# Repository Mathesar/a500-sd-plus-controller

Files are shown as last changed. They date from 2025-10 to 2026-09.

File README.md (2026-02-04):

# a500-sd-plus-controller
This is a dual micro-SD card plus Ethernet controller for the Amiga 500.
The controller piggybacks on the odd CIA (CIA A) chip on the Amiga 500 motherboard.

## Table of Contents
* [Micro-SD](#micro-sd)
* [Ethernet](#ethernet)
* [Drivers](#drivers)
* [Performance](#performance)
* [Pictures](#pictures)
* [Building](#building)

## Micro-SD
The two Micro-SD cards are operated in SPI mode.
Using the 68000 movep (move to/from peripheral) instruction and optimized code the driver reaches a raw throughput of up to 450kB/s on a standard 7MHz 68000 CPU. Due to device driver and filesystem overhead the overall speed is lower though.

The primary channel is intended for internal use. The micro-SD card in this slot functions as a fixed harddisk. The secondary channel is intended to be used with an extension cable to hold an external (hot-swappable if the driver supports it) micro-SD card. 
For this purpose, proper measures are taken to control signal integrity over the extension cable. The controller can also handle any current surges that can occur during hot swapping without overloading the Amiga power rail.

## Ethernet
The Ethernet controller is a Microchip ENC28J60 device. It is also connected over SPI and uses the INT2 interrupt. The ENC28J60 supports a 10Mbit network connection.
The interface is built in a slightly non-standard way to maximum immunity for external interference.

## Drivers
The Micro-SD cards are supported by [sd-lide.device](https://github.com/Mathesar/sd_lide.device).

The Ethernet controller is supported by [enc28j60.device](https://github.com/Mathesar/enc28j60.device).

## Performance
On a standard Amiga 500 with a 7MHz 68000 CPU running OS3.1 and AmiTCP 3.0b2 the following performance is reached:

* 250kB/s read speed for the Micro-SD cards as reported by SysInfo.
* Up to 22kB/s network download speed which is mostly limited by CPU speed.

Much better performance which is only limited by the speed of the E-clk (~600..700kB/s) can be expected when a faster CPU is installed.

## Pictures
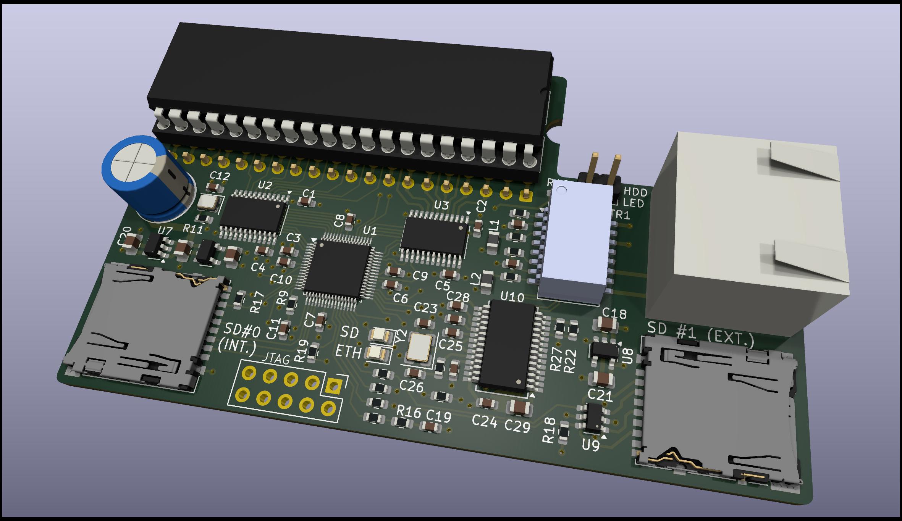
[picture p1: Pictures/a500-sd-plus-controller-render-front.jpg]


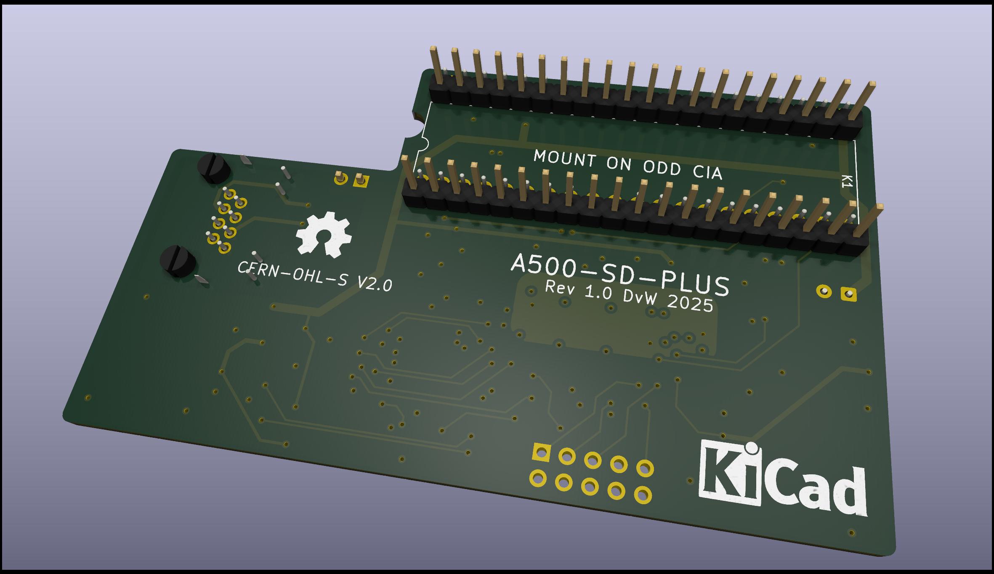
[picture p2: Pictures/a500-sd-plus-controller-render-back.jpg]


Proof that this was actually built:
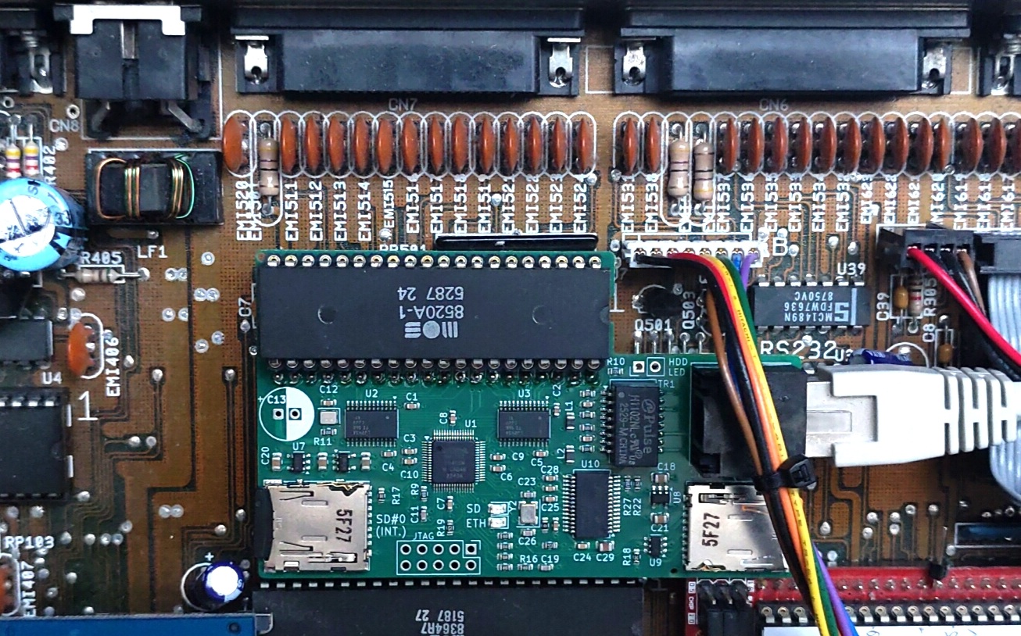
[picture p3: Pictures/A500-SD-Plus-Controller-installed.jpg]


And the obligatory SysInfo screenshot:
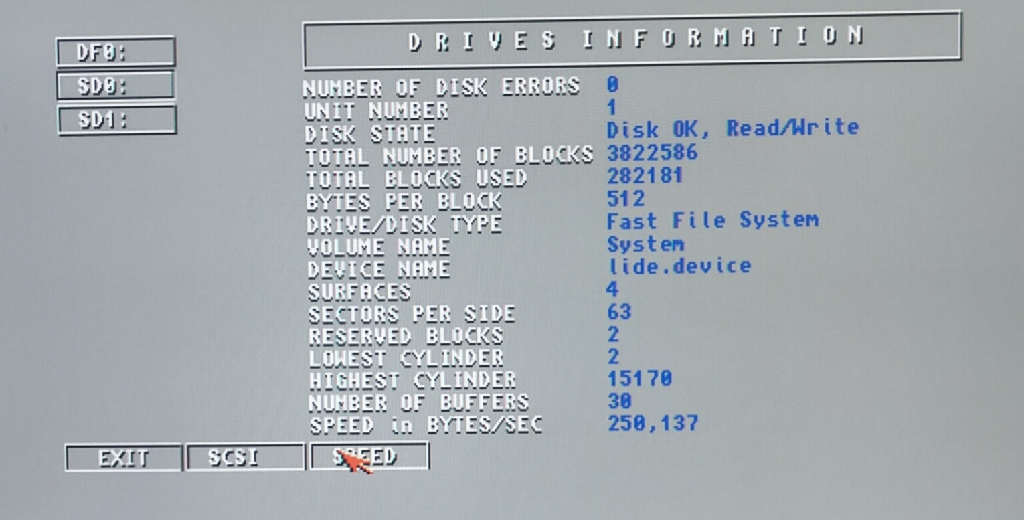
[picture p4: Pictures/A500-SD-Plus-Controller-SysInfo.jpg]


## Building
Under [releases](https://github.com/Mathesar/a500-sd-plus-controller/releases) you will find the latest gerbers, bill of materials, bitstream, etc.
The files are in a format that is suitable for most well-known PCBA manufacturers.
I would recommend having the boards soldered professionally. This project uses small compononents and especially the CPLD is not solderable by hand. I had the boards made with all the SMD parts and the ethernet connector mounted. I only soldered the pinheaders and the CIA socket myself. For the pinheaders that plug into the CIA socket on the A500 motherboard, be sure to use the THIN and ROUND (aka "turned") pinheaders. Otherwise the motherboard socket WILL be damaged.

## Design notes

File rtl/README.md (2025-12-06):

# a500-sd-plus-controller
The SPI controller communicates via the unused register of the odd 8520 CIA at address $BFEB01

| **address** | **R/W** | **Name** |
| --- | --- | --- |
| $BFEB01 | R/W | SPI controller |

All communication with the SPI controller is done via this single register.
The behavior of this register depends on the state the SPI controller is in.

Additionally, a simple IRQ controller is included that is able to mask interrupts from the ENC28J60 Ethernet controller.

## States
The SPI controller can be in any of the following states:

| **State** | **Read** | **Write** |
| --- | --- | --- |
| IDLE | read busy flag | issue command |
| READ | read buffer and shift | return to **IDLE** |
| WRITE | read buffer and return to **IDLE** | write buffer and shift |
| CRC | read crc | return to **IDLE** |

### IDLE state
In this state, commands can be send the the SPI controller.
After reset, the controller will be in this state.
A command is 1 byte long. 
The following commands are supported:

| **command** | **format**  | **description** |
| --- | --- | --- |
| NOP | 0b000x_xxxx | does nothing |
| CONTROL | 0b001x_xxDD | write control register with 0bDD |
| SELECT | 0b010x_xDDD | write select register with 0bDDD |
| CRC_SOURCE  | 0b011x_xxxD | write crc-source register with 0bD |
| READ | 0b100x_xxxx | goto READ state |
| WRITE | 0b101x_xxxx | goto WRITE state |
| CRC | 0b110x_xxxx | goto CRC state |

When in IDLE mode, a read will return the busy flag in the highest bit (bit#7), the other bits are undefined and should thus be masked out and ignored. 
When the busy flag is set, the controller is doing an SPI transaction and no data should be read from or written to the buffer.

#### select register
This register controls the chip select signals. 
This register is set to all zeroes after reset.
Writing a '1' to a corresponding bit asserts (sets low) the corresponding chip select signal. Only 1 device at a time should be asserted.

| **Bit:** | 2 | 1 | 0 |
| --- | --- | ---- | ---- |
| **Device** | Ethernet | SD 1 | SD 0 |

#### control register
This register controls the configuration of the SPI controller.
This register is set to all zeroes after reset.
Currently, only the SPI clock speed can be set.

| **value** | **clock speed** |
| --- | --- |
| 0b00 | 242 kHz |
| 0b01 | 1.6 MHz |
| 0b10 | 8 MHz |

#### crc-source register
This register selects MOSI or MISO as the CRC generator input. 
This register is set to all zeroes after reset.
Changing the source (writing to this register) also resets the CRC generator to 0x0000.

| **value** | **source** |
| --- | --- |
| 0b0 | MOSI (compute CRC on write) |
| 0b1 | MISO (compute CRC on read)  |

### READ state
This mode is used to read consecutive bytes from the SPI interface.
Each read cycle return the buffer (which contains the last shifted in data) and starts a new SPI transaction. During this transaction, 1's are shifted out regardless of the buffer contents. When the highest speed is selected, data can be read consecutively without checking the busy flag for maximum throughput. For reading a single byte, the WRITE state should be used.

### WRITE state
This mode is used to write a single byte or consecutive bytes to the SPI interface.
Each write cycle writes the buffer and starts a new SPI transaction. During this transaction. When the highest speed is selected, data can be written consecutively without checking the busy flag for maximum throughput.
A read cycle returns the current buffer contents and also returns to the IDLE state.
This way, single bytes can be read as writing in the READ state will always trigger a new SPI transaction.

### CRC state
This mode is used to read the CRC register. The CRC register is 16bits wide. After entering this state from IDLE using the proper command, code should read 2 bytes after which the controller will automatically return to the IDLE state. The first byte read is the high byte of the CRC register. The second byte read is the low byte of the CRC register.

## Some command sequences

### Init sequence, return to IDLE state from an unknown state
```
READ			// return to IDLE state if in CRC or WRITE state
WRITE 0x00  	// if we were now in READ state, return to IDLE state
				// if we are now in IDLE state, issue NOP command
```

### Read a single byte
```
WRITE 0xA0			// go to WRITE state
WRITE 0xFF			// start an SPI transaction while shifting out 1's
READ 				// return to IDLE
while READ&0x80;	// loop while busy set
WRITE 0xA0			// go to WRITE state
READ data;			// read data
```

### Write a single byte
```
WRITE 0xA0			// go to WRITE state
WRITE data			// start an SPI transaction while shifting out data
READ 				// return to IDLE
while READ&0x80;	// loop while busy set
```

## IRQ controller
The IRQ controller allows masking of the ENC28J60 interrupt.
The IRQ controller communicates via the unused bit5 of the odd 8520 CIA's IRC register at address $BFED01

| 7 | 6 | 5 | 4 | 3 | 2 | 1 | 0 |
| --- | --- | --- | --- | --- | --- | --- | --- |
| S/C | | ETH | FLG | SERIAL | TOD | TB  | TA  |

It is not possible to read if the Ethernet interrupt bit was set as this will also clear the CIA's interrupts. So, the Ethernet driver shall only write to this bit.

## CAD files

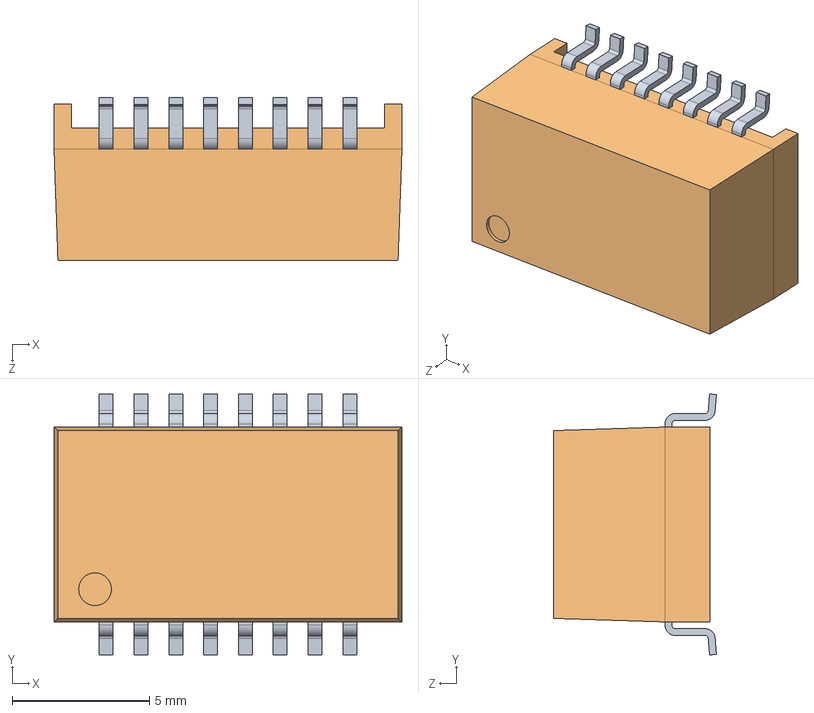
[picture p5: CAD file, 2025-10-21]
kicad/a500-sd-plus-controller/3d/H1102NLT.step
12.7 x 9.53 x 5.94 mm

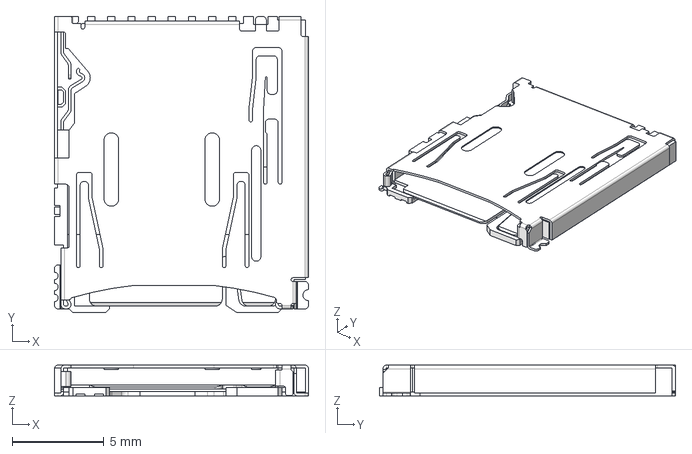
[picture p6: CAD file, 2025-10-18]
kicad/a500-sd-plus-controller/3d/DM3AT-SF-PEJM5.stp
13.8 x 16.2 x 1.68 mm

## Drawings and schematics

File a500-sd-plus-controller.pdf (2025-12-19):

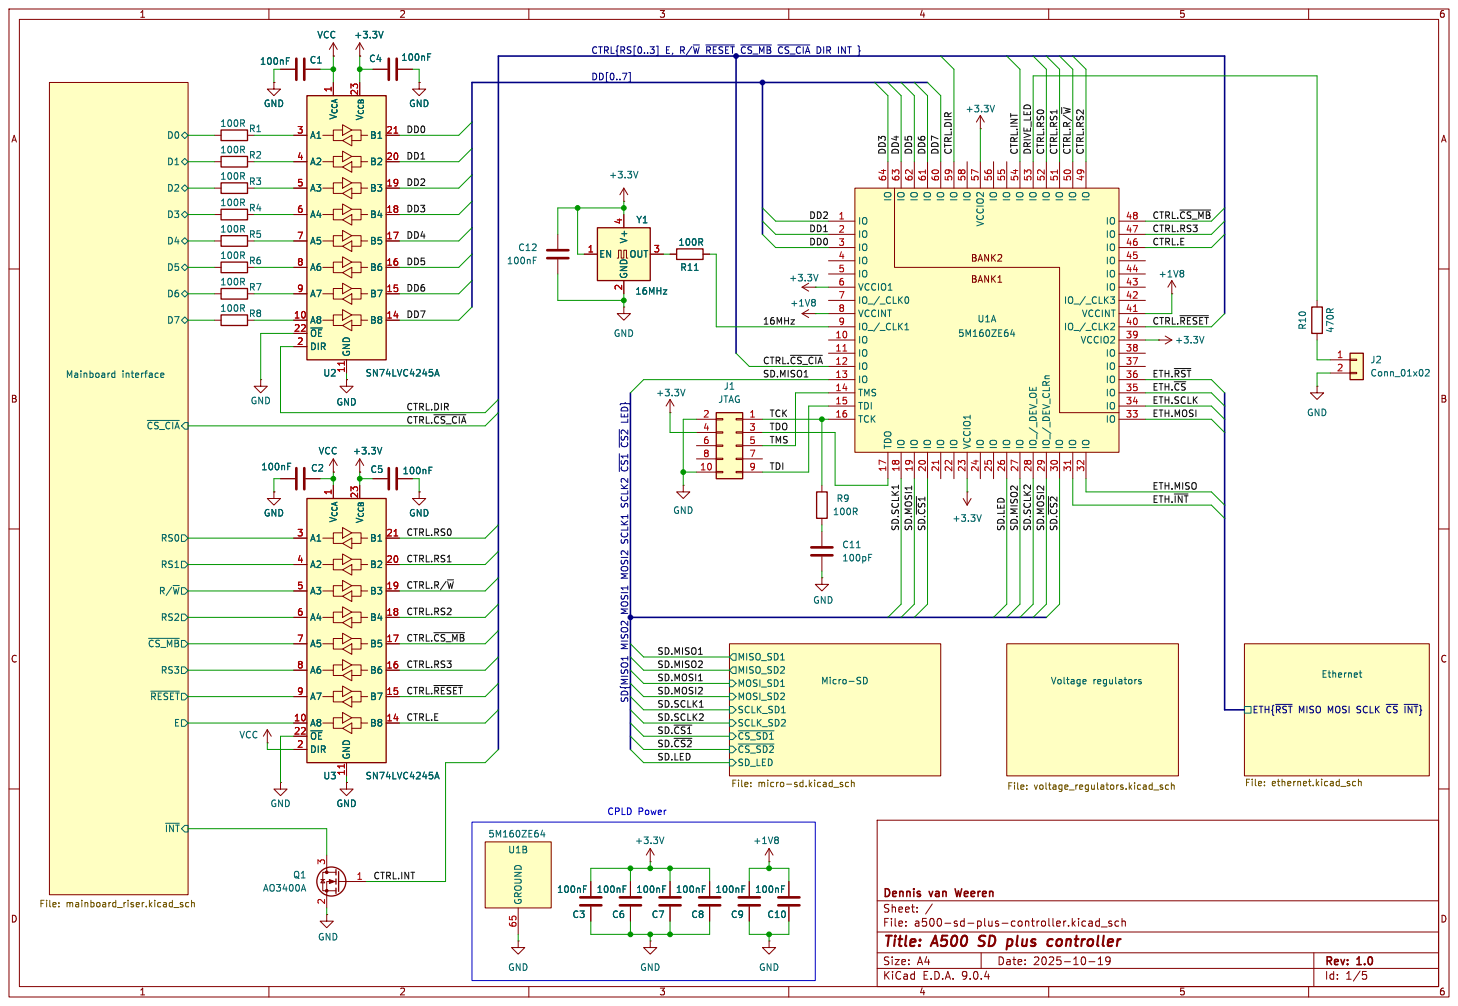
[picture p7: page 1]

SD.MISO1 CTRL.~{CS_CIA} TDI DD[0..7]

CTRL.~{RESET} CTRL.RS3 CTRL.~{CS_MB} CTRL.RS1 CTRL.E CTRL.DIR

ETH.~{RST} SD.~{CS2} SD{MISO1 MISO2 MOSI1 MOSI2 SCLK1 SCLK2 ~{CS1}~{CS2}LED}

ETH{~{RST}MISO MOSI SCLK ~{CS}~{INT}} Ethernet File: ethernet.kicad_sch MISO_SD1 MISO_SD2 MOSI_SD1 MOSI_SD2 SCLK_SD1 SCLK_SD2 ~{CS_SD1}

File: micro-sd.kicad_sch GND

Id: 1/5 Title: A500 SD plus controller File: a500-sd-plus-controller.kicad_sch Sheet: / Dennis van Weeren

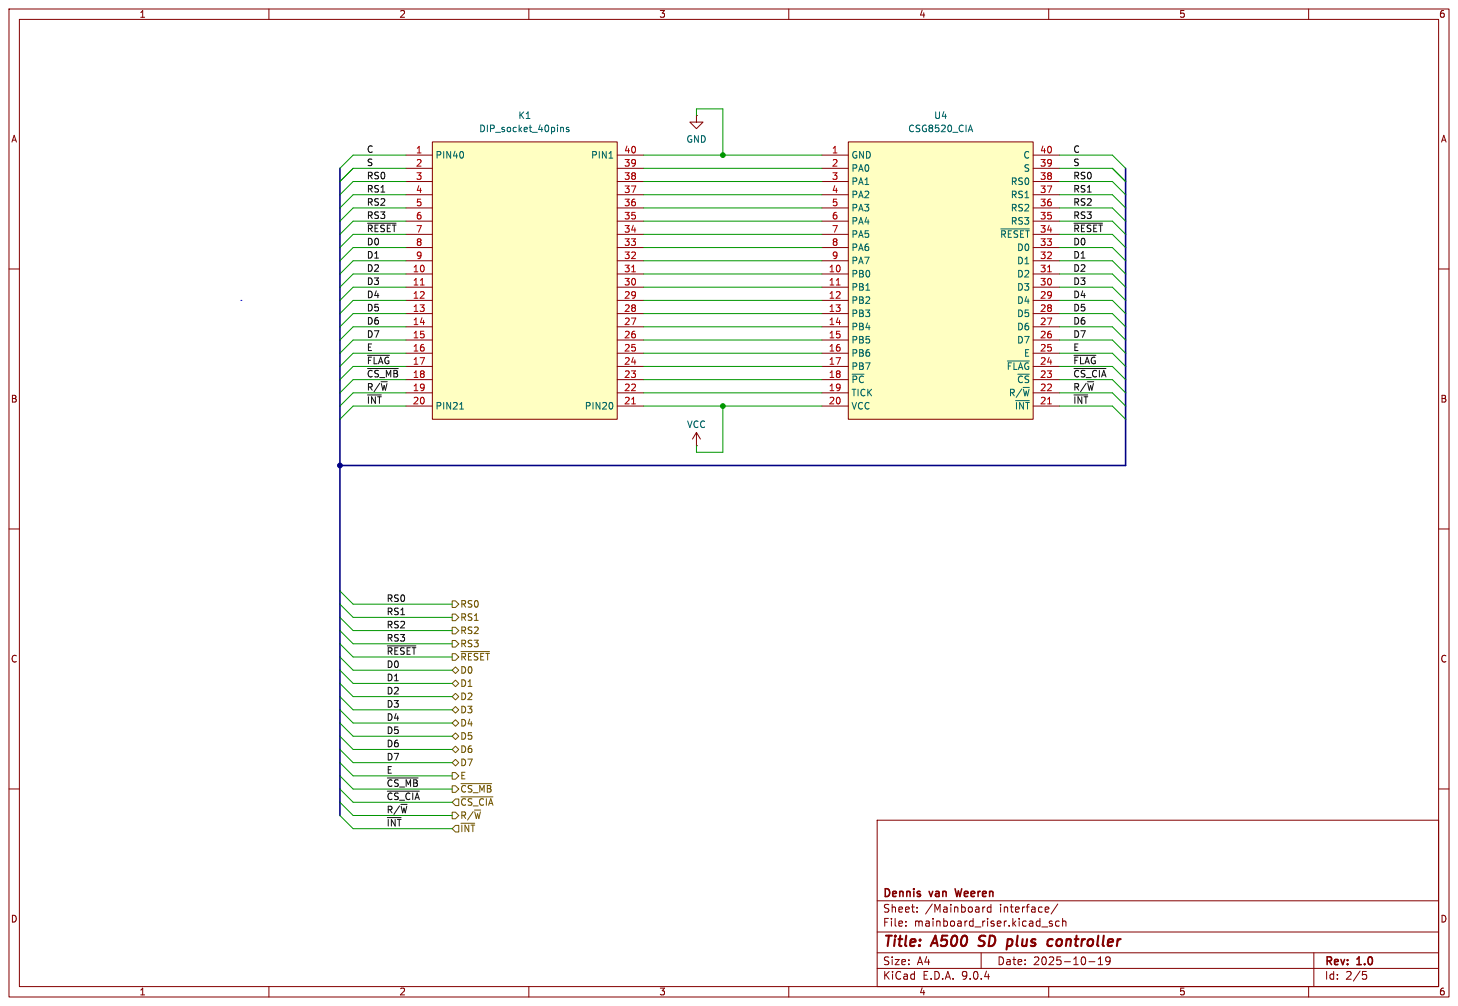
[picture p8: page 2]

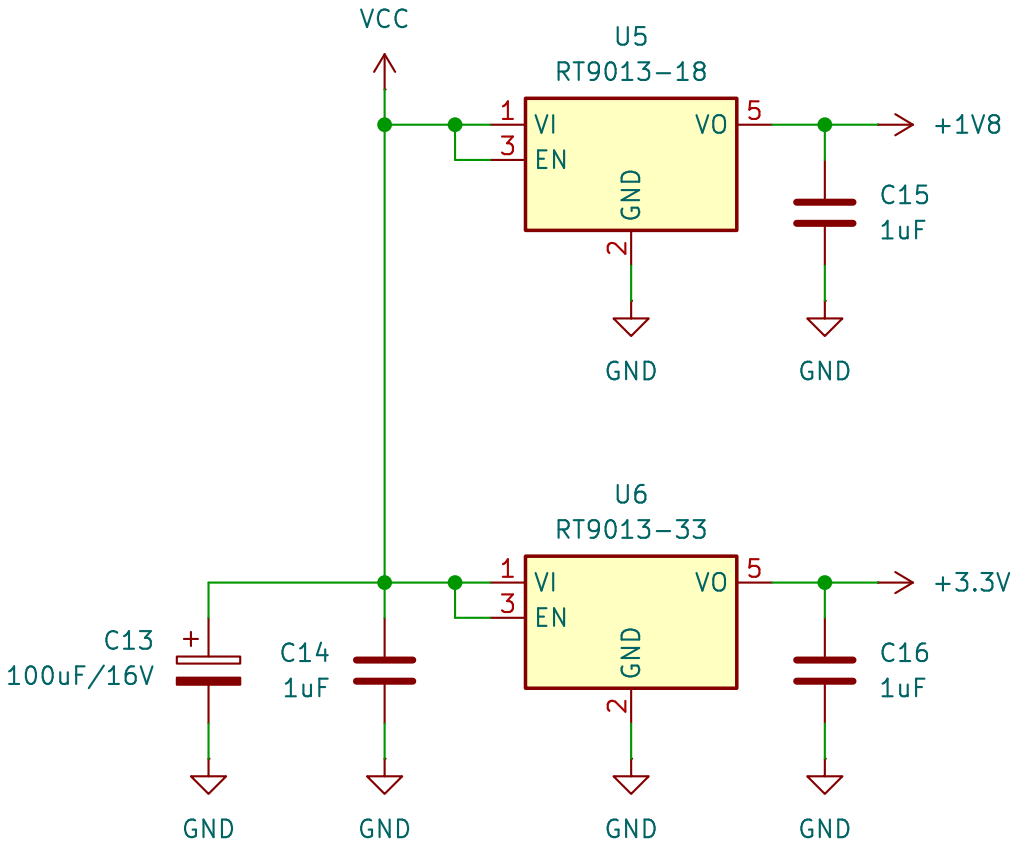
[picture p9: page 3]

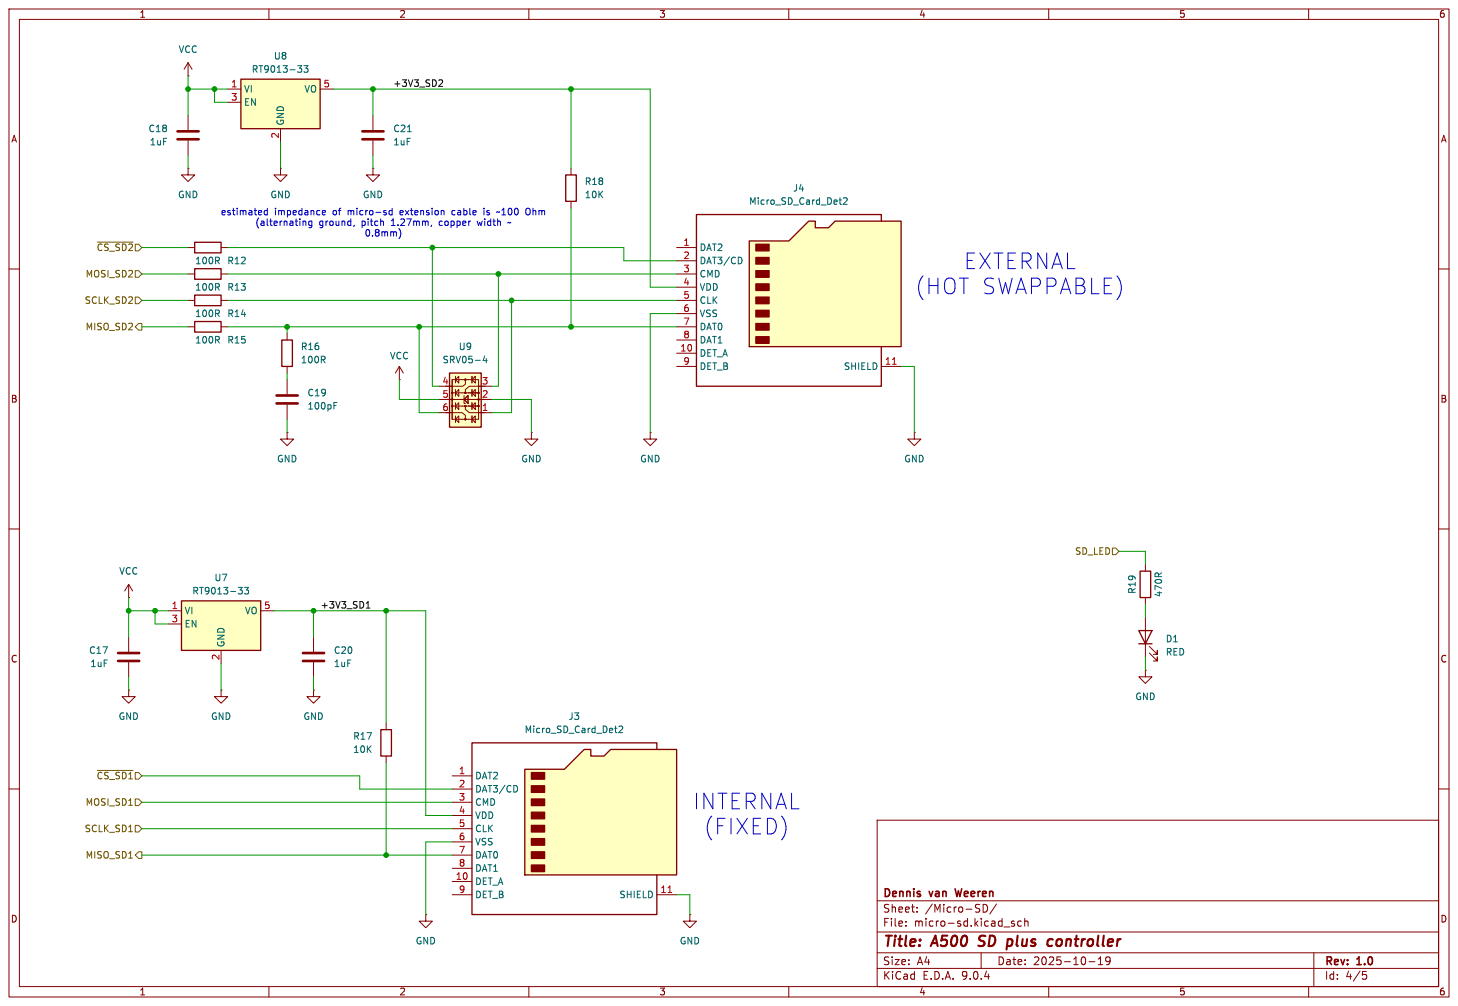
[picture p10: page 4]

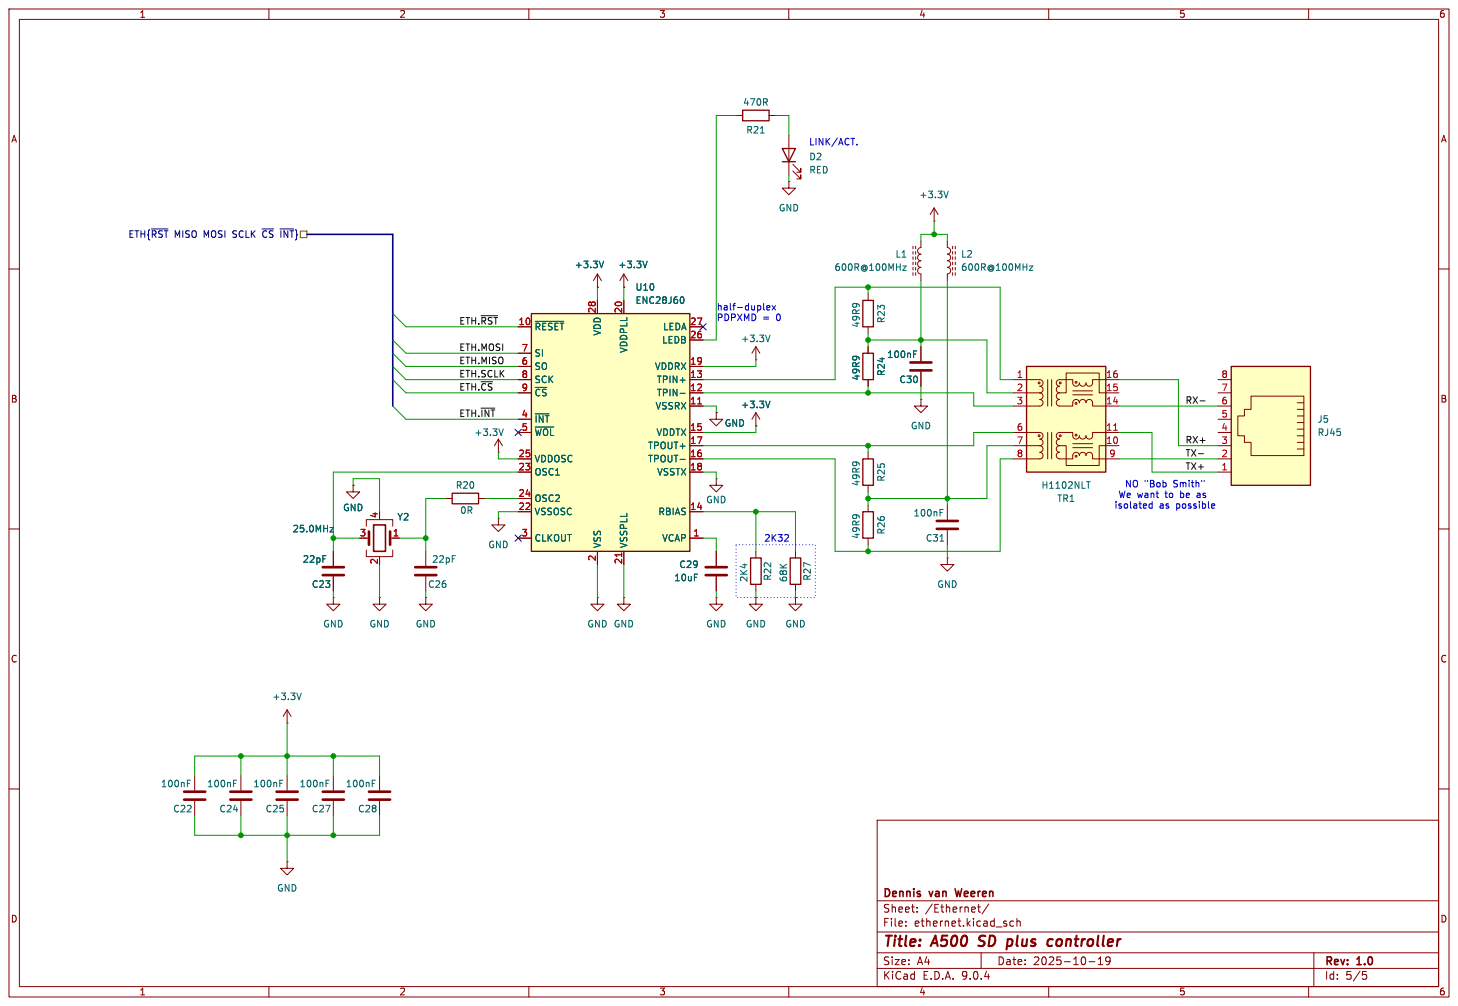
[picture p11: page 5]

Id: 5/5 Title: A500 SD plus controller File: ethernet.kicad_sch Sheet: /Ethernet/ Dennis van Weeren C25

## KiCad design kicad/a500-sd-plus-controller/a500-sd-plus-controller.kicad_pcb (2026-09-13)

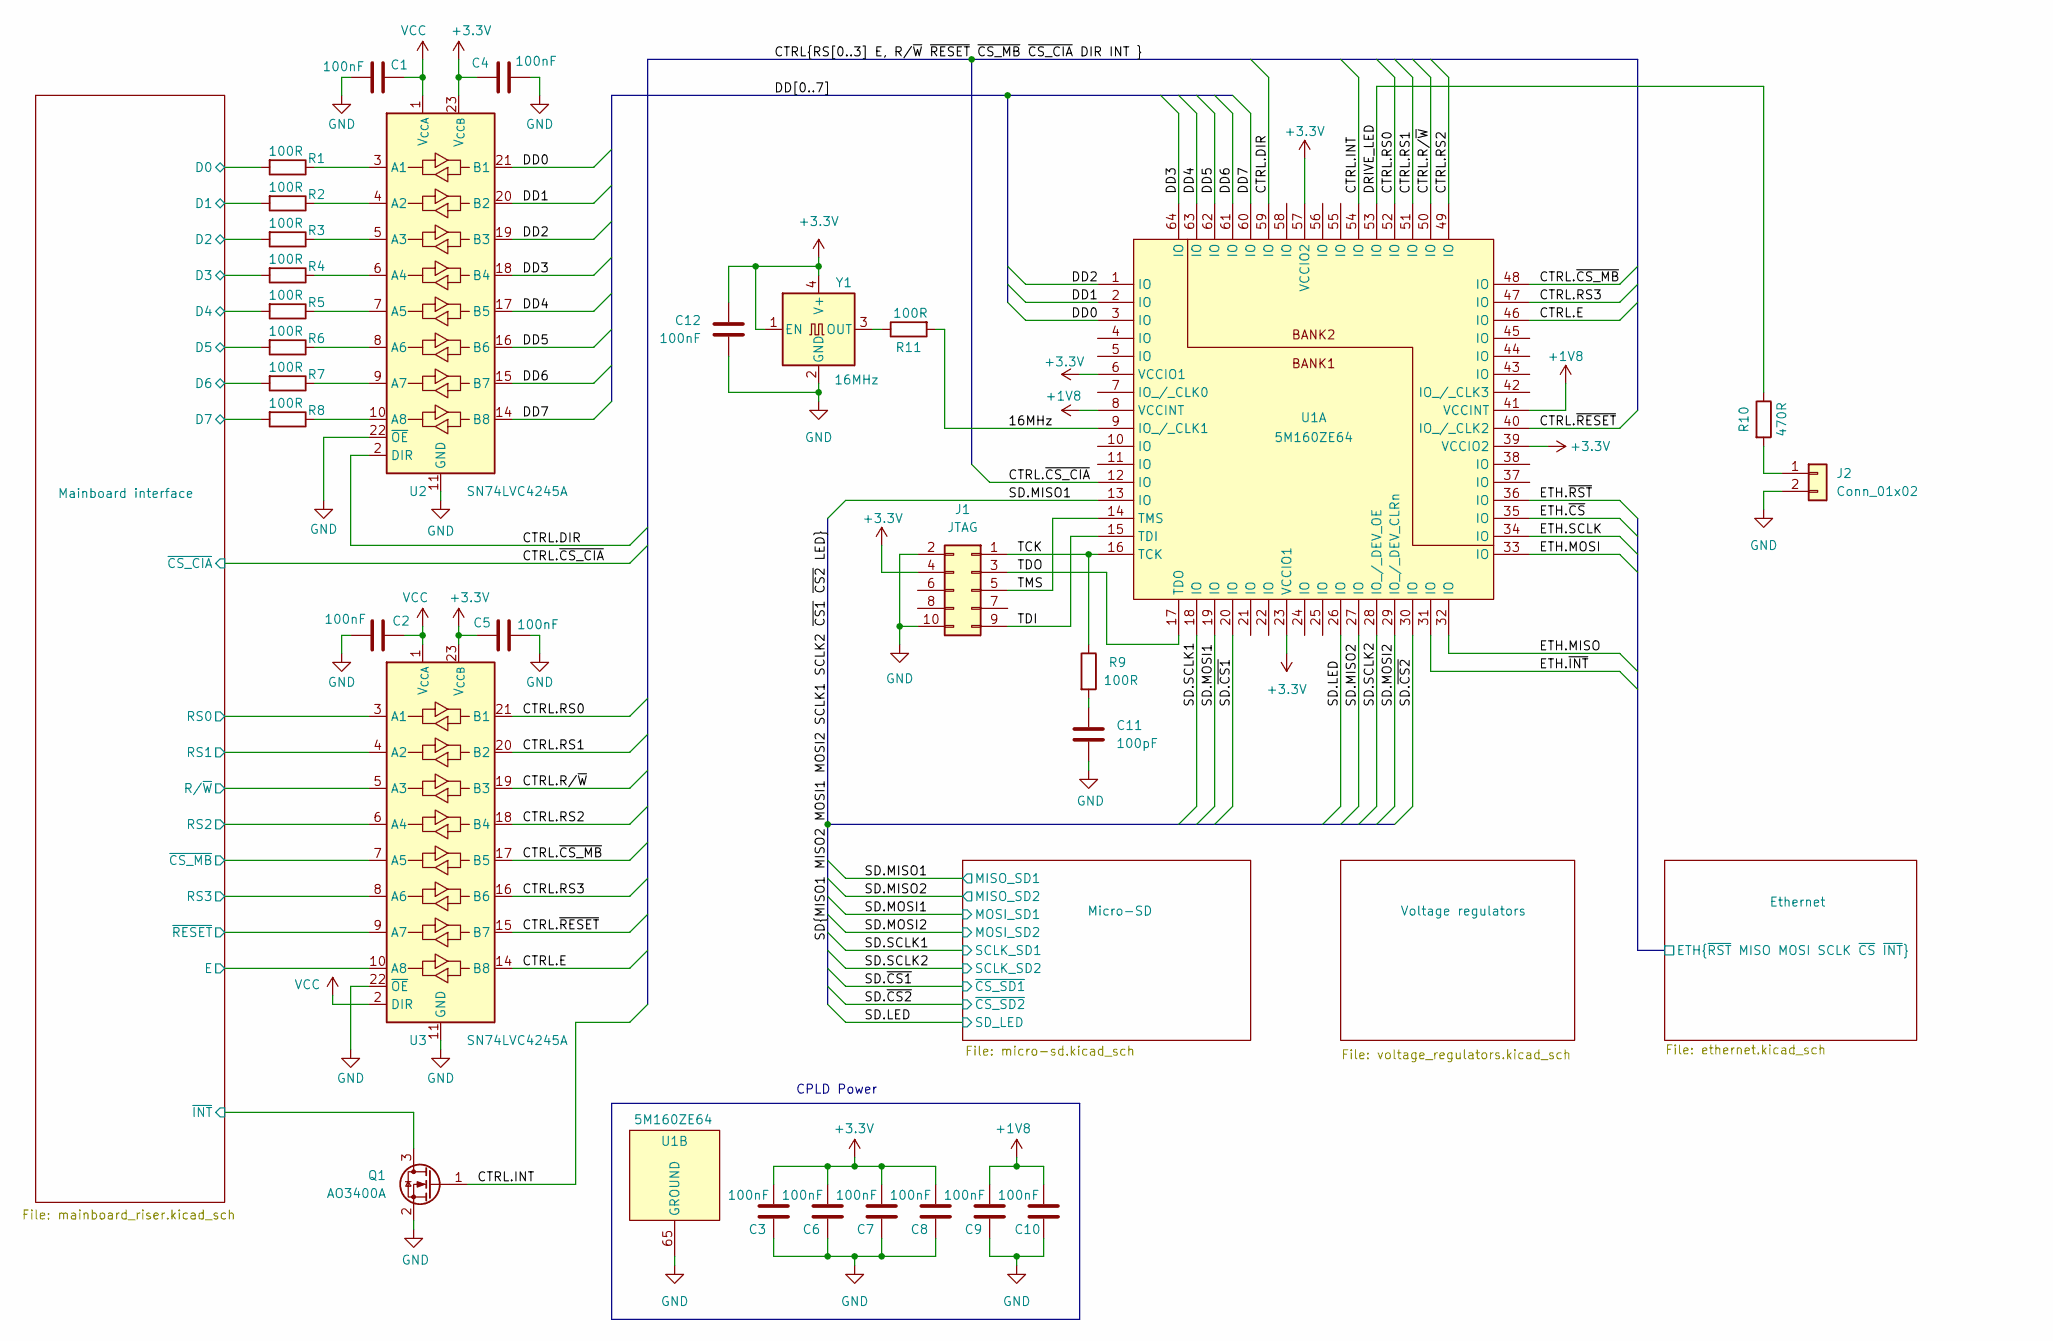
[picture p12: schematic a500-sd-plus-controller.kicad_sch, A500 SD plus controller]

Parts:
C1, C2, C3, C4, C5, C6, C7, C8, C9, C10, C12: 100nF; C_0603_1608Metric; LCSC Part # C14663
C11: 100pF; C_0603_1608Metric; LCSC Part # C14858
J1: JTAG; PinHeader_2x05_P2.54mm_Vertical
J2: Conn_01x02; PinHeader_1x02_P2.54mm_Vertical
Q1: AO3400A; SOT-23; MPN AO3400A; LCSC Part # C20917
R1, R2, R3, R4, R5, R6, R7, R8, R9, R11: 100R; R_0603_1608Metric; LCSC Part # C22775
R10: 470R; R_0603_1608Metric; LCSC Part # C23179
U1: 5M160ZE64; EQFP-64_7x7mm_P0.4mm; MPN 5M160ZE64C5N; LCSC Part # C431489
U2, U3: SN74LVC4245A; TSSOP-24_4.4x7.8mm_P0.65mm; MPN SN74LVC4245APWR; LCSC Part # C7859
Y1: 16MHz; Oscillator_SMD_SeikoEpson_SG210-4Pin_2.5x2.0mm; MPN X1G0041710027; LCSC Part # C255993

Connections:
+1V8: C9.1, C10.1, U1.8 (VCCINT), U1.41 (VCCINT); also elsewhere on the board
+3.3V: C3.1, C4.2, C5.2, C6.1, C7.1, C8.1, C12.2, J1.4, U1.6 (VCCIO1), U1.23 (VCCIO1), U1.39 (VCCIO2), U1.57 (VCCIO2), U2.23 (V_{CCB}), U2.24 (V_{CCB}), U3.23 (V_{CCB}), U3.24 (V_{CCB}), Y1.1 (EN), Y1.4 (V+); also elsewhere on the board
/16MHz: R11.2, U1.9 (IO_/_CLK1)
/CTRL.DIR: U1.59 (IO), U2.2 (DIR)
/CTRL.E: U1.46 (IO), U3.14 (B8)
/CTRL.INT: Q1.1 (G), U1.54 (IO)
/CTRL.RS0: U1.52 (IO), U3.21 (B1)
/CTRL.RS1: U1.51 (IO), U3.20 (B2)
/CTRL.RS2: U1.49 (IO), U3.18 (B4)
/CTRL.RS3: U1.47 (IO), U3.16 (B6)
/CTRL.R/~W: U1.50 (IO), U3.19 (B3)
/CTRL.~CS_CIA: U1.12 (IO); also elsewhere on the board
/CTRL.~CS_MB: U1.48 (IO), U3.17 (B5)
/CTRL.~RESET: U1.40 (IO_/_CLK2), U3.15 (B7)
/DD0: U1.3 (IO), U2.21 (B1)
/DD1: U1.2 (IO), U2.20 (B2)
/DD2: U1.1 (IO), U2.19 (B3)
/DD3: U1.64 (IO), U2.18 (B4)
/DD4: U1.63 (IO), U2.17 (B5)
/DD5: U1.62 (IO), U2.16 (B6)
/DD6: U1.61 (IO), U2.15 (B7)
/DD7: U1.60 (IO), U2.14 (B8)
/DRIVE_LED: R10.1, U1.53 (IO)
/Ethernet/ETH.MISO: U1.32 (IO); also elsewhere on the board
/Ethernet/ETH.MOSI: U1.33 (IO); also elsewhere on the board
/Ethernet/ETH.SCLK: U1.34 (IO); also elsewhere on the board
/Ethernet/ETH.~CS: U1.35 (IO); also elsewhere on the board
/Ethernet/ETH.~INT: U1.31 (IO); also elsewhere on the board
/Ethernet/ETH.~RST: U1.36 (IO); also elsewhere on the board
/Mainboard interface/D0: R1.2; also elsewhere on the board
/Mainboard interface/D1: R2.2; also elsewhere on the board
/Mainboard interface/D2: R3.2; also elsewhere on the board
/Mainboard interface/D3: R4.2; also elsewhere on the board
/Mainboard interface/D4: R5.2; also elsewhere on the board
/Mainboard interface/D5: R6.2; also elsewhere on the board
/Mainboard interface/D6: R7.2; also elsewhere on the board
/Mainboard interface/D7: R8.2; also elsewhere on the board
/Mainboard interface/E: U3.10 (A8); also elsewhere on the board
/Mainboard interface/RS0: U3.3 (A1); also elsewhere on the board
/Mainboard interface/RS1: U3.4 (A2); also elsewhere on the board
/Mainboard interface/RS2: U3.6 (A4); also elsewhere on the board
/Mainboard interface/RS3: U3.8 (A6); also elsewhere on the board
/Mainboard interface/R/~W: U3.5 (A3); also elsewhere on the board
/Mainboard interface/~CS_MB: U3.7 (A5); also elsewhere on the board
/Mainboard interface/~INT: Q1.3 (D); also elsewhere on the board
/Mainboard interface/~RESET: U3.9 (A7); also elsewhere on the board
/SD.LED: U1.26 (IO); also elsewhere on the board
/SD.MISO1: U1.13 (IO); also elsewhere on the board
/SD.MISO2: U1.27 (IO); also elsewhere on the board
/SD.MOSI1: U1.19 (IO); also elsewhere on the board
/SD.MOSI2: U1.29 (IO_/_DEV_CLRn); also elsewhere on the board
/SD.SCLK1: U1.18 (IO); also elsewhere on the board
/SD.SCLK2: U1.28 (IO_/_DEV_OE); also elsewhere on the board
/SD.~CS1: U1.20 (IO); also elsewhere on the board
/SD.~CS2: U1.30 (IO); also elsewhere on the board
/TCK: J1.1, R9.1, U1.16 (TCK)
/TDI: J1.9, U1.15 (TDI)
/TDO: J1.3, U1.17 (TDO)
/TMS: J1.5, U1.14 (TMS)
GND: C1.1, C2.1, C3.2, C4.1, C5.1, C6.2, C7.2, C8.2, C9.2, C10.2, C11.1, C12.1, J1.2, J1.10, J2.2, Q1.2 (S), U1.65 (GROUND), U2.11 (GND), U2.12 (GND), U2.13 (GND), U2.22 (~OE), U3.11 (GND), U3.12 (GND), U3.13 (GND), U3.22 (~OE), Y1.2 (GND); also elsewhere on the board
unnamed: C11.2, R9.2
unnamed: J2.1, R10.2
unnamed: R1.1, U2.3 (A1)
unnamed: R2.1, U2.4 (A2)
unnamed: R3.1, U2.5 (A3)
unnamed: R4.1, U2.6 (A4)
unnamed: R5.1, U2.7 (A5)
unnamed: R6.1, U2.8 (A6)
unnamed: R7.1, U2.9 (A7)
unnamed: R8.1, U2.10 (A8)
unnamed: R11.1, Y1.3 (OUT)
VCC: C1.2, C2.2, U2.1 (V_{CCA}), U3.1 (V_{CCA}), U3.2 (DIR); also elsewhere on the board

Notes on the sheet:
CPLD Power

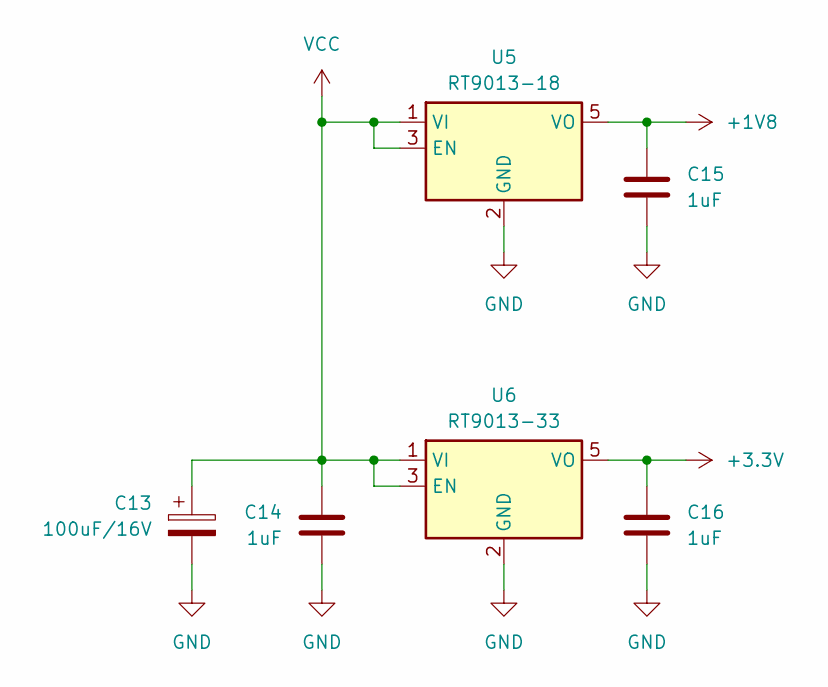
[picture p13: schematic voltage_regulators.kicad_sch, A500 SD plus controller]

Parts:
C13: 100uF/16V; CP_Radial_D8.0mm_P2.50mm; MPN EH71CM101E07OT; LCSC Part # C112487
C14, C15, C16: 1uF; C_0805_2012Metric; LCSC Part # C28323
U5: RT9013-18; SOT-23-5; MPN RT9013-18GB; LCSC Part # C22435116
U6: RT9013-33; SOT-23-5; MPN TPRT9013-33GB; LCSC Part # C587158

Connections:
+1V8: C15.2, U5.5 (VO); also elsewhere on the board
+3.3V: C16.2, U6.5 (VO); also elsewhere on the board
GND: C13.2, C14.1, C15.1, C16.1, U5.2 (GND), U6.2 (GND); also elsewhere on the board
VCC: C13.1, C14.2, U5.1 (VI), U5.3 (EN), U6.1 (VI), U6.3 (EN); also elsewhere on the board

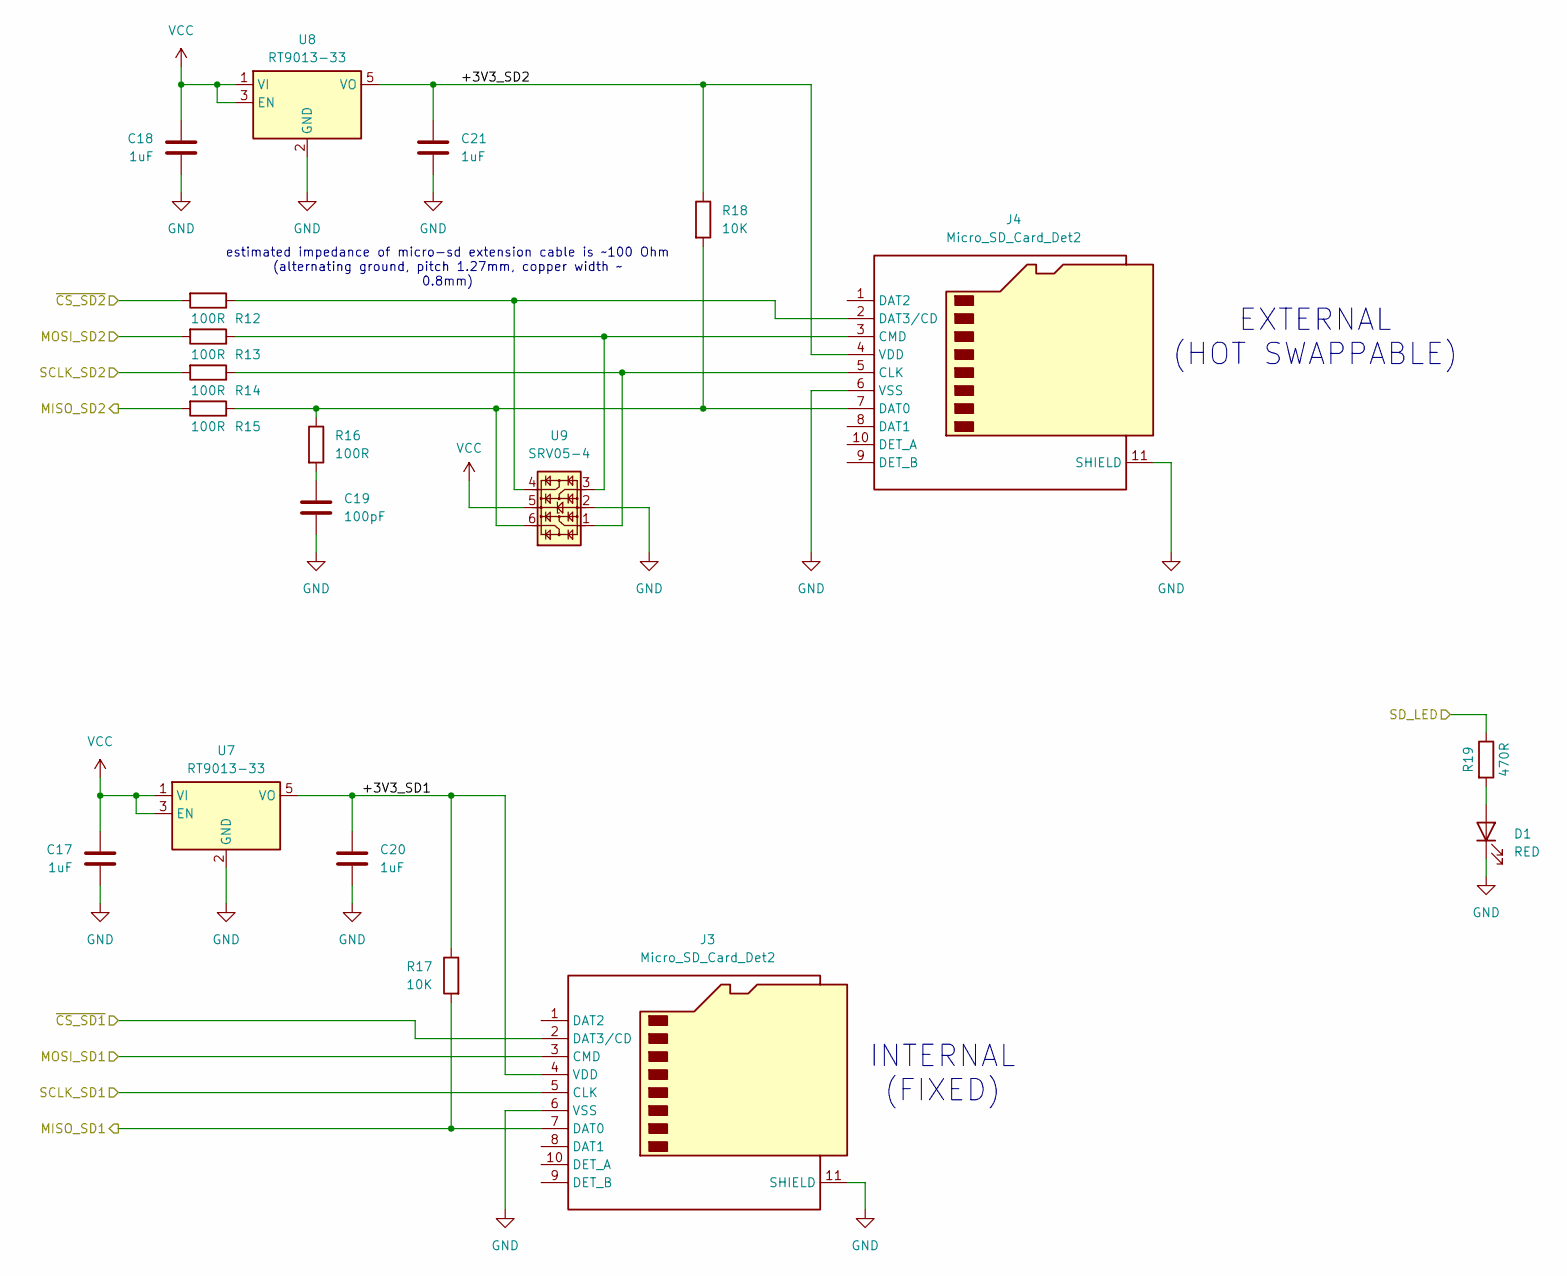
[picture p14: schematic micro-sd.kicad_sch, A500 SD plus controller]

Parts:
C17, C18, C20, C21: 1uF; C_0805_2012Metric; LCSC Part # C28323
C19: 100pF; C_0603_1608Metric; LCSC Part # C14858
D1: RED; LED_0805_2012Metric; MPN NCD0805R1; LCSC Part # C84256
J3, J4: Micro_SD_Card_Det2; microSD_HC_Hirose_DM3AT-SF-PEJM5; MPN DM3AT-SF-PEJM5; LCSC Part # C114218
R12, R13, R14, R15, R16: 100R; R_0603_1608Metric; LCSC Part # C22775
R17, R18: 10K; R_0603_1608Metric; LCSC Part # C25804
R19: 470R; R_0603_1608Metric; LCSC Part # C23179
U7, U8: RT9013-33; SOT-23-5; MPN TPRT9013-33GB; LCSC Part # C587158
U9: SRV05-4; SOT-23-6; MPN SRV05-4; LCSC Part # C2836319

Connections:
/Micro-SD/+3V3_SD1: C20.2, J3.4 (VDD), R17.1, U7.5 (VO)
/Micro-SD/+3V3_SD2: C21.2, J4.4 (VDD), R18.1, U8.5 (VO)
/SD.LED: R19.1; also elsewhere on the board
/SD.MISO1: J3.7 (DAT0), R17.2; also elsewhere on the board
/SD.MISO2: R15.2; also elsewhere on the board
/SD.MOSI1: J3.3 (CMD); also elsewhere on the board
/SD.MOSI2: R13.2; also elsewhere on the board
/SD.SCLK1: J3.5 (CLK); also elsewhere on the board
/SD.SCLK2: R14.2; also elsewhere on the board
/SD.~CS1: J3.2 (DAT3/CD); also elsewhere on the board
/SD.~CS2: R12.2; also elsewhere on the board
GND: C17.1, C18.1, C19.1, C20.1, C21.1, D1.1 (K), J3.6 (VSS), J3.11 (SHIELD), J4.6 (VSS), J4.11 (SHIELD), U7.2 (GND), U8.2 (GND), U9.2; also elsewhere on the board
unnamed: C19.2, R16.2
unnamed: D1.2 (A), R19.2
unnamed: J4.5 (CLK), R14.1, U9.1
unnamed: J4.3 (CMD), R13.1, U9.3
unnamed: J4.7 (DAT0), R15.1, R16.1, R18.2, U9.6
unnamed: J4.2 (DAT3/CD), R12.1, U9.4
VCC: C17.2, C18.2, U7.1 (VI), U7.3 (EN), U8.1 (VI), U8.3 (EN), U9.5; also elsewhere on the board

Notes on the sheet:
INTERNAL (FIXED)
EXTERNAL (HOT SWAPPABLE)
estimated impedance of micro-sd extension cable is ~100 Ohm (alternating ground, pitch 1.27mm, copper width ~ 0.8mm)

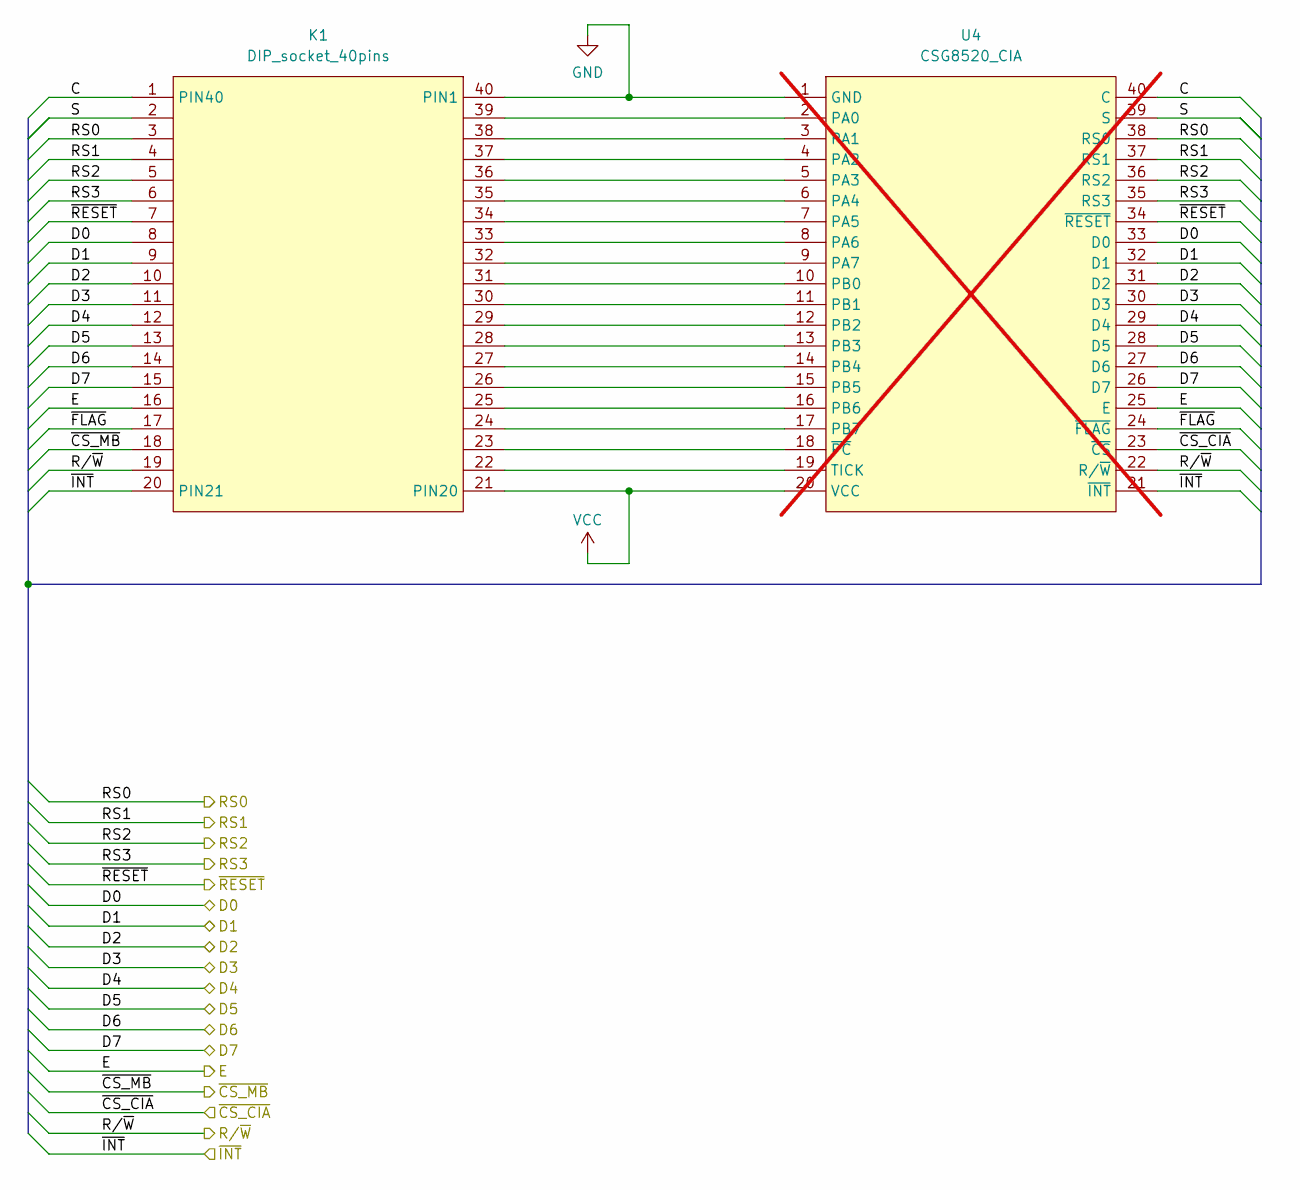
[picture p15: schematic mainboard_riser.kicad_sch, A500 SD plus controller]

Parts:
K1: DIP_socket_40pins; DIP-40_W15.24mm
U4: CSG8520_CIA; DIP-40_W15.24mm; not fitted

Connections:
/CTRL.~CS_CIA: U4.23 (~CS); also elsewhere on the board
/Mainboard interface/C: K1.1 (PIN40), U4.40 (C)
/Mainboard interface/D0: K1.8, U4.33 (D0); also elsewhere on the board
/Mainboard interface/D1: K1.9, U4.32 (D1); also elsewhere on the board
/Mainboard interface/D2: K1.10, U4.31 (D2); also elsewhere on the board
/Mainboard interface/D3: K1.11, U4.30 (D3); also elsewhere on the board
/Mainboard interface/D4: K1.12, U4.29 (D4); also elsewhere on the board
/Mainboard interface/D5: K1.13, U4.28 (D5); also elsewhere on the board
/Mainboard interface/D6: K1.14, U4.27 (D6); also elsewhere on the board
/Mainboard interface/D7: K1.15, U4.26 (D7); also elsewhere on the board
/Mainboard interface/E: K1.16, U4.25 (E); also elsewhere on the board
/Mainboard interface/RS0: K1.3, U4.38 (RS0); also elsewhere on the board
/Mainboard interface/RS1: K1.4, U4.37 (RS1); also elsewhere on the board
/Mainboard interface/RS2: K1.5, U4.36 (RS2); also elsewhere on the board
/Mainboard interface/RS3: K1.6, U4.35 (RS3); also elsewhere on the board
/Mainboard interface/R/~W: K1.19, U4.22 (R/~W); also elsewhere on the board
/Mainboard interface/S: K1.2, U4.39 (S)
/Mainboard interface/~CS_MB: K1.18; also elsewhere on the board
/Mainboard interface/~FLAG: K1.17, U4.24 (~FLAG)
/Mainboard interface/~INT: K1.20 (PIN21), U4.21 (~INT); also elsewhere on the board
/Mainboard interface/~RESET: K1.7, U4.34 (~RESET); also elsewhere on the board
GND: K1.40 (PIN1), U4.1 (GND); also elsewhere on the board
unnamed: K1.39, U4.2 (PA0)
unnamed: K1.38, U4.3 (PA1)
unnamed: K1.37, U4.4 (PA2)
unnamed: K1.36, U4.5 (PA3)
unnamed: K1.35, U4.6 (PA4)
unnamed: K1.34, U4.7 (PA5)
unnamed: K1.33, U4.8 (PA6)
unnamed: K1.32, U4.9 (PA7)
unnamed: K1.31, U4.10 (PB0)
unnamed: K1.30, U4.11 (PB1)
unnamed: K1.29, U4.12 (PB2)
unnamed: K1.28, U4.13 (PB3)
unnamed: K1.27, U4.14 (PB4)
unnamed: K1.26, U4.15 (PB5)
unnamed: K1.25, U4.16 (PB6)
unnamed: K1.24, U4.17 (PB7)
unnamed: K1.22, U4.19 (TICK)
unnamed: K1.23, U4.18 (~PC)
VCC: K1.21 (PIN20), U4.20 (VCC); also elsewhere on the board

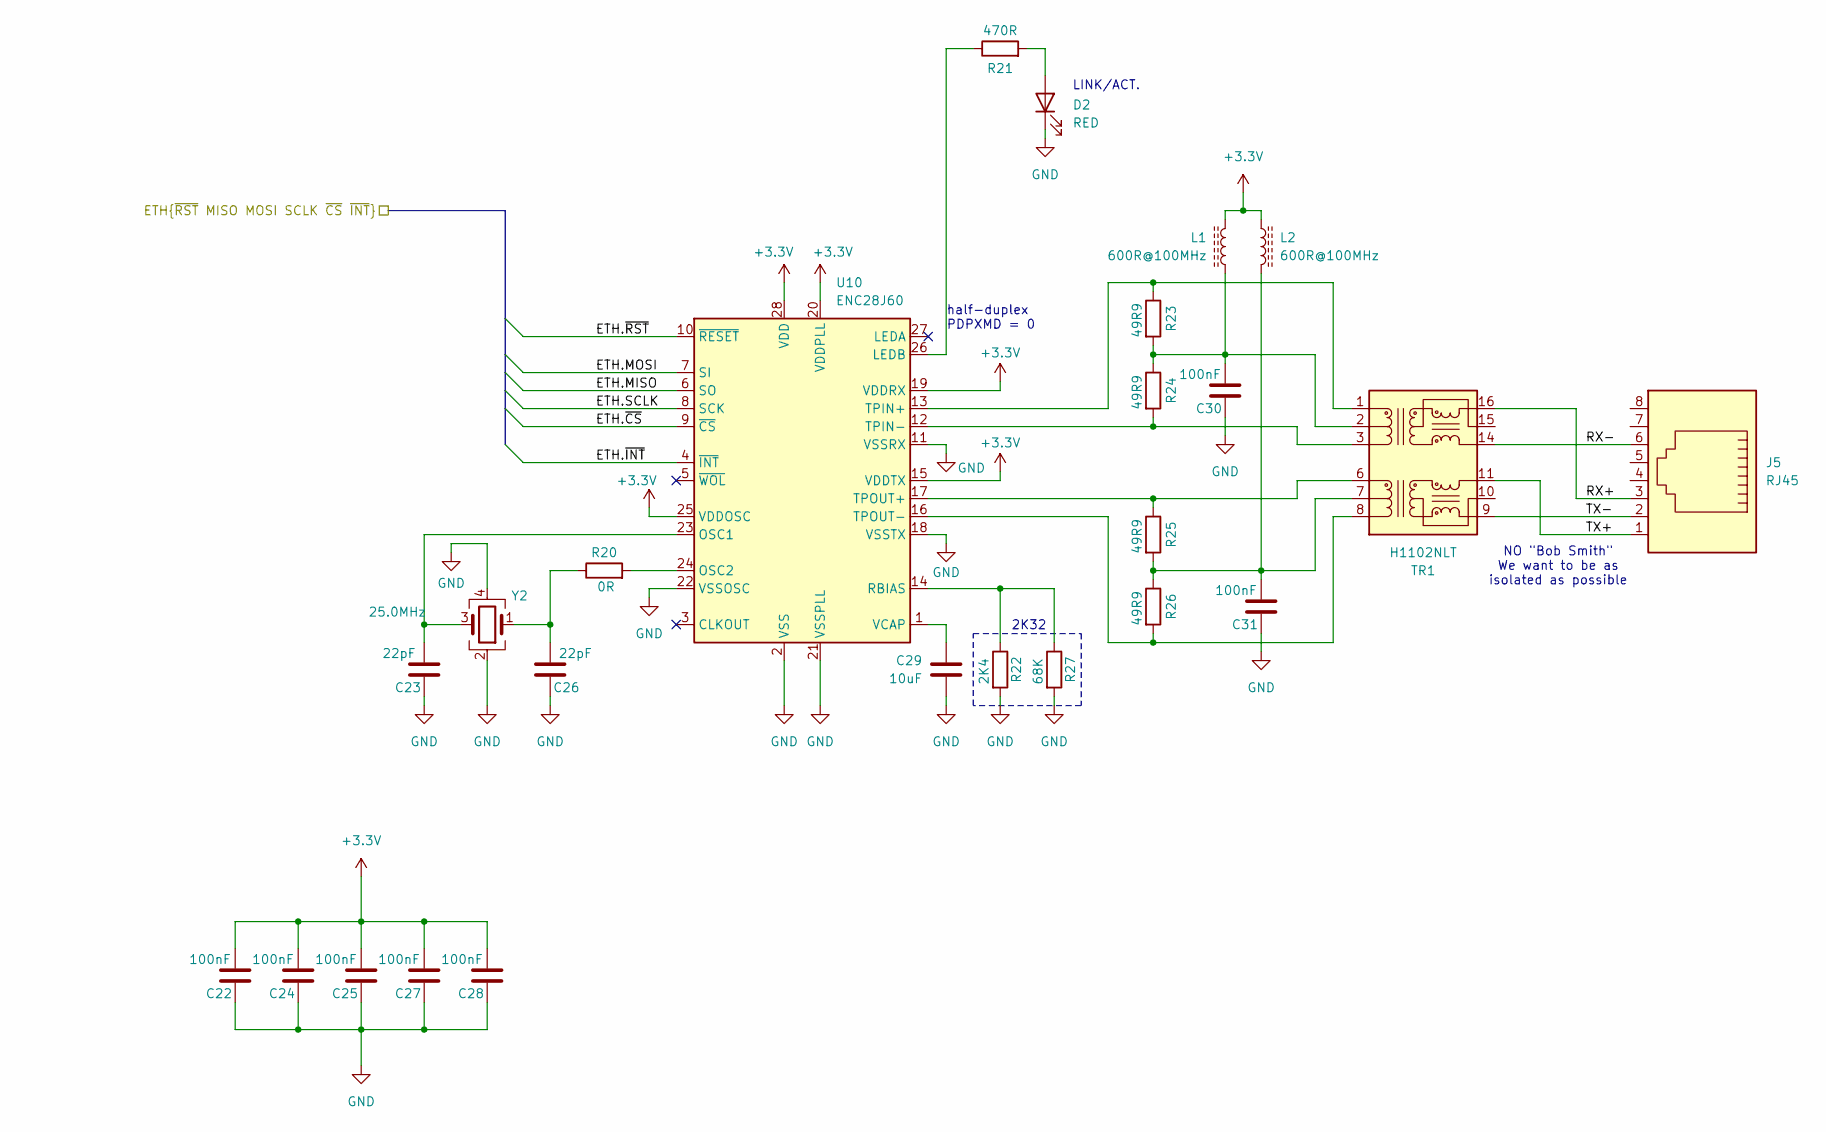
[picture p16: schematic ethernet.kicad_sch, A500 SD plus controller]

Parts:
C22, C24, C25, C27, C28, C30, C31: 100nF; C_0603_1608Metric; LCSC Part # C14663
C23, C26: 22pF; C_0603_1608Metric; LCSC Part # C1653
C29: 10uF; C_0805_2012Metric; LCSC Part # C15850
D2: RED; LED_0805_2012Metric; MPN NCD0805R1; LCSC Part # C84256
J5: RJ45; R-RJ45R08P-A004; MPN R-RJ45R08P-A004; LCSC Part # C385834
L1, L2: 600R@100MHz; L_0805_2012Metric; MPN GZ2012D601TF; LCSC Part # C1017
R20: 0R; R_0603_1608Metric; LCSC Part # C21189
R21: 470R; R_0603_1608Metric; LCSC Part # C23179
R22: 2K4; R_0603_1608Metric; LCSC Part # C22940
R23, R24, R25, R26: 49R9; R_0603_1608Metric; LCSC Part # C23185
R27: 68K; R_0603_1608Metric; LCSC Part # C23231
TR1: H1102NLT; Transformer_Ethernet_Bourns_PT61017PEL; MPN H1102NLT; LCSC Part # C18584
U10: ENC28J60; SSOP-28_5.3x10.2mm_P0.65mm; MPN ENC28J60-I/SS; LCSC Part # C411626
Y2: 25.0MHz; Crystal_SMD_SeikoEpson_FA238V-4Pin_3.2x2.5mm; MPN X322525MOB4SI; LCSC Part # C9006

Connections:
+3.3V: C22.1, C24.1, C25.1, C27.1, C28.1, L1.1, L2.1, U10.15 (VDDTX), U10.19 (VDDRX), U10.20 (VDDPLL), U10.25 (VDDOSC), U10.28 (VDD); also elsewhere on the board
/Ethernet/ETH.MISO: U10.6 (SO); also elsewhere on the board
/Ethernet/ETH.MOSI: U10.7 (SI); also elsewhere on the board
/Ethernet/ETH.SCLK: U10.8 (SCK); also elsewhere on the board
/Ethernet/ETH.~CS: U10.9 (~CS); also elsewhere on the board
/Ethernet/ETH.~INT: U10.4 (~INT); also elsewhere on the board
/Ethernet/ETH.~RST: U10.10 (~RESET); also elsewhere on the board
/Ethernet/RX+: J5.3, TR1.16 (TX+)
/Ethernet/RX-: J5.6, TR1.14 (TX-)
/Ethernet/TX+: J5.1, TR1.11 (RX+)
/Ethernet/TX-: J5.2, TR1.9 (RX-)
GND: C22.2, C23.2, C24.2, C25.2, C26.2, C27.2, C28.2, C29.1, C30.2, C31.2, D2.1 (K), R22.2, R27.2, U10.2 (VSS), U10.11 (VSSRX), U10.18 (VSSTX), U10.21 (VSSPLL), U10.22 (VSSOSC), Y2.2, Y2.4; also elsewhere on the board
unnamed: C26.1, R20.1, Y2.1
unnamed: D2.2 (A), R21.2
unnamed: C31.1, L2.2, R25.2, R26.1, TR1.7 (C_RD)
unnamed: C30.1, L1.2, R23.2, R24.1, TR1.2 (C_TD)
unnamed: R25.1, TR1.6 (RD+), U10.17 (TPOUT+)
unnamed: R26.2, TR1.8 (RD-), U10.16 (TPOUT-)
unnamed: R23.1, TR1.1 (TD+), U10.13 (TPIN+)
unnamed: R24.2, TR1.3 (TD-), U10.12 (TPIN-)
unnamed: R21.1, U10.26 (LEDB)
unnamed: C23.1, U10.23 (OSC1), Y2.3
unnamed: R20.2, U10.24 (OSC2)
unnamed: R22.1, R27.1, U10.14 (RBIAS)
unnamed: C29.2, U10.1 (VCAP)

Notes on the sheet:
LINK/ACT.
NO "Bob Smith" We want to be as isolated as possible
2K32
half-duplex PDPXMD = 0

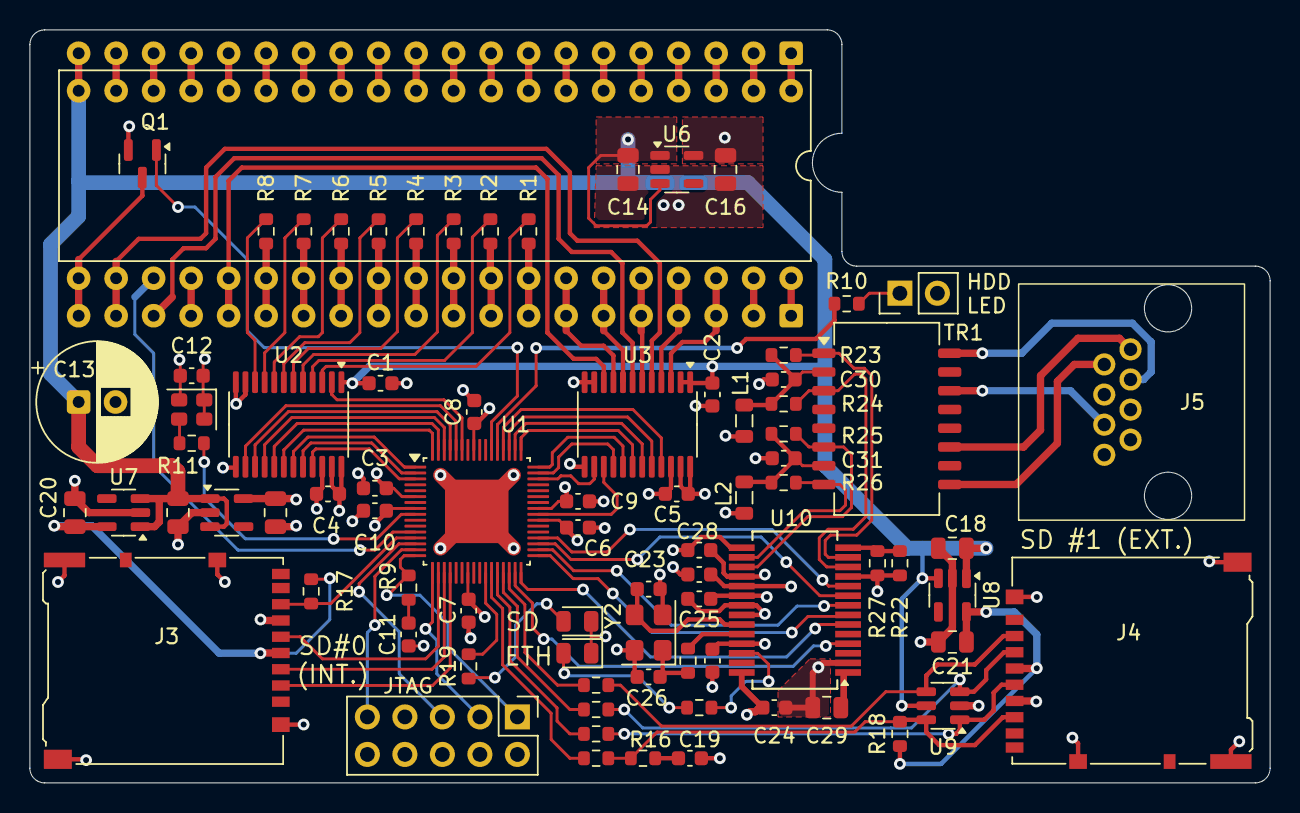
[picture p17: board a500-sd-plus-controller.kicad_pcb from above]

Board: 4 copper layers, 84.0 x 51.0 mm, 82 parts (1 on the bottom side), 118 nets.

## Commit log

2025-09-19 passing testbench, 68K bus is now handled asynchronously from
    synchronous core SPI logic
2025-09-29 started work on hardware
    [a500-sd-plus-controller.kicad_pcb, a500-sd-plus-controller.kicad_sch, mainboard_riser.kicad_sch]
2025-10-18 more work done on hardware
    basic schematic done
    layout in progress
    [DM3AT-SF-PEJM5.stp, a500-sd-plus-controller.csv, a500-sd-plus-controller.kicad_pcb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]
2025-10-19 added add ethernet controller
    still work in progress
    [a500-sd-plus-controller.kicad_pcb, a500-sd-plus-controller.kicad_sch, ethernet.kicad_sch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]
2025-10-21 routing completely done
    todo: review footprints and cleanup silkscreen
    [H1102NLT.step, a500-sd-plus-controller.kicad_pcb, a500-sd-plus-controller.kicad_sch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]
2025-10-22 cleaned up silkscreen and 3D models
    [a500-sd-plus-controller.kicad_pcb, a500-sd-plus-controller.kicad_sch, ethernet.kicad_sch]
2025-10-25 PCB done, this version has been sent to fabrication
    [a500-sd-plus-controller.csv, a500-sd-plus-controller.kicad_pcb, a500-sd-plus-controller.kicad_sch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]
2025-10-26 fixed a bug where async r/w signal was used in statemachine
    external bus driver is now enabled before internal driver to avoid clashes
    code cleanup
2025-11-02 moved busy flag to highest bit so that driver code can use
    68K "tst.b (a1)" instruction and branch on negative flag
2025-11-09 fixed polarity of SD/HDD LEDs
2025-12-04 added interrupt controller to enable/disable interrupt
2025-12-19 added schematics
2025-12-19 Added links to drivers.
2026-09-07 Fill in C13 sourcing, flag U4 as not-populated, thicken thin silkscreen
    Three small fixes found while preparing a fabrication package.
    C13 (100uF/16V) was the only part in the schematic with neither an MPN nor
    an LCSC part number, so any assembly quote stalls on it. Added AISHI
    EH71CM101E07OT / C112487: 100uF 16V, 6.3mm diameter, 2.5mm lead pitch,
    7mm seated height. That fits CP_Radial_D8.0mm_P2.50mm with margin and is
    the shortest 16V part in that pitch, which matters given how little room
    there is above the board.
    U4 is the 8520 CIA harvested from the A500 motherboard -- its pads are
    where the turned pin headers go, and no assembly house should ever place
    it. Marked DNP in the schematic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
    [a500-sd-plus-controller.kicad_pcb, mainboard_riser.kicad_sch, voltage_regulators.kicad_sch]
2026-09-13 updated BOM changes in PCB file
    [a500-sd-plus-controller.kicad_pcb]

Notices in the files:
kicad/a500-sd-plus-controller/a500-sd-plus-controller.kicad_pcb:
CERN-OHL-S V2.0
